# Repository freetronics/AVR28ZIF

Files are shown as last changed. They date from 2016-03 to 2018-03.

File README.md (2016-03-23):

Freetronics 28-Pin AVR ZIF Breakout
===================================
Copyright 2016 Freetronics Pty Ltd  
Freetronics site:  www.freetronics.com  
Freetronics email: info@freetronics.com  

Breakout for a 28-pin ZIF (Zero Insertion Force) for AVR microcontrollers,
with headers for ICSP and USB-to-Serial connections. Includes an onboard
crystal and LED on Arduino pin D13.

Features:

 * 28-pin ZIF socket
 * Header for FTDI-compatible USB-to-Serial cable
 * Header for 6-pin ICSP cable
 * Power source selection jumper
 * Power LED
 * LED on Arduino pin D13
 * Crystal and capacitors
 * Reset button

More information is available at:

  http://www.freetronics.com/avr28zif

INSTALLATION
------------
The design is saved as an EAGLE project. EAGLE PCB design software is
available from www.cadsoftusa.com free for non-commercial use. To use
this project download it and place the directory containing these files
into the "eagle" directory on your computer.

DISTRIBUTION
------------
The specific terms of distribution of this project are governed by the
license referenced below.

LICENSE
-------
Licensed under the TAPR Open Hardware License (www.tapr.org/OHL).
The "license" folder within this repository also contains a copy of
this license in plain text format.

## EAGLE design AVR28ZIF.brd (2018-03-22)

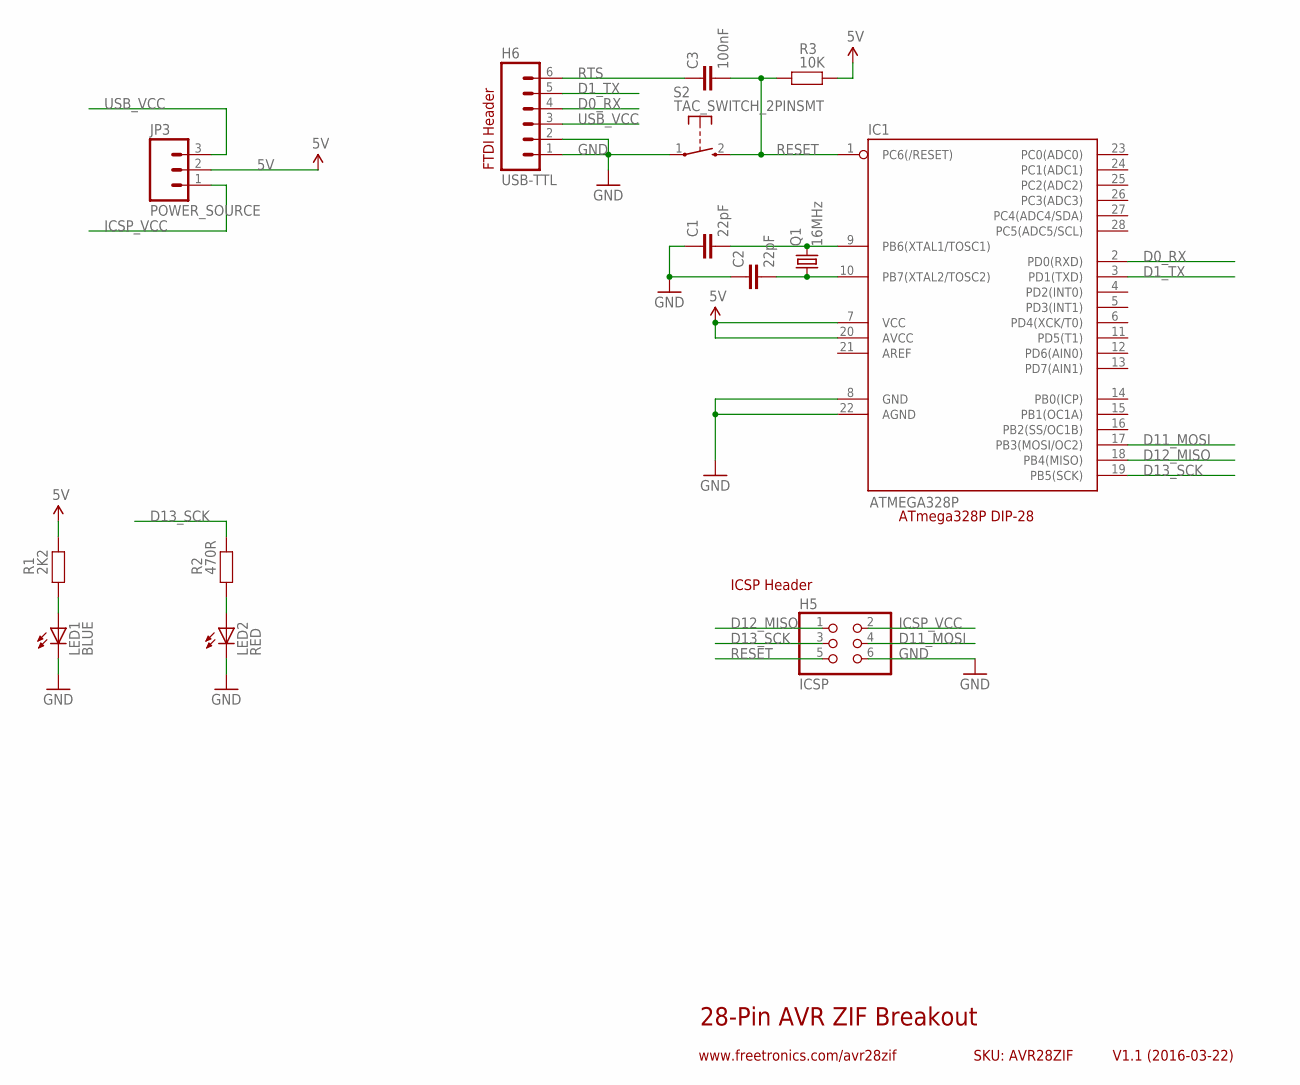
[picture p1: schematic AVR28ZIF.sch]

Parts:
C1, C2: 22pF; 0603
C3: 100nF; 0603
H5: ICSP; 2X03
H6: USB-TTL; 1X06
IC1: ATMEGA328P; DIL28-3-ZIF
JP3: POWER_SOURCE; 1X03
LED1: BLUE; LED-0603
LED2: RED; LED-0603
Q1: 16MHz; HC49US
R1: 2K2; 0603
R2: 470R; 0603
R3: 10K; 0603
S2: TAC_SWITCH_2PINSMT; TACTILE_SWITCH_SMD_2PIN_TINY

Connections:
5V: IC1.7 (VCC), IC1.20 (AVCC), JP3.2, R1.2, R3.2
D0_RX: H6.4, IC1.2 (PD0(RXD))
D1_TX: H6.5, IC1.3 (PD1(TXD))
D11_MOSI: H5.4, IC1.17 (PB3(MOSI/OC2))
D12_MISO: H5.1, IC1.18 (PB4(MISO))
D13_SCK: H5.3, IC1.19 (PB5(SCK)), R2.2
GND: C1.1, C2.1, H5.6, H6.1, H6.2, IC1.8 (GND), IC1.22 (AGND), LED1.C, LED2.C, S2.1
ICSP_VCC: H5.2, JP3.1
unnamed: C1.2, IC1.9 (PB6(XTAL1/TOSC1)), Q1.2
unnamed: C2.2, IC1.10 (PB7(XTAL2/TOSC2)), Q1.1
unnamed: LED1.A, R1.1
unnamed: LED2.A, R2.1
RESET: C3.2, H5.5, IC1.1 (PC6(/RESET)), R3.1, S2.2 (S)
RTS: C3.1, H6.6
USB_VCC: H6.3, JP3.3

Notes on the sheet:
28-Pin AVR ZIF Breakout
V1.1 (2016-03-22)
SKU: AVR28ZIF
www.freetronics.com/avr28zif
ATmega328P DIP-28
ICSP Header
FTDI Header

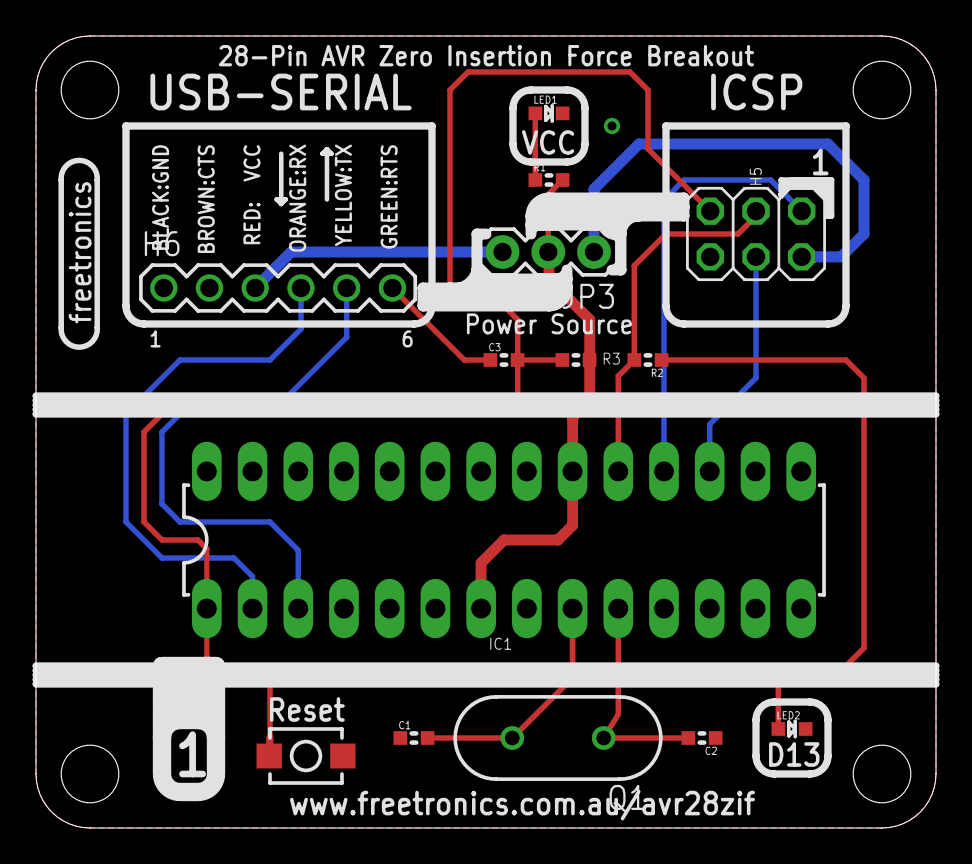
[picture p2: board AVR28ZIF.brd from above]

Board: 2 copper layers, 50.0 x 44.0 mm, 14 parts (0 on the bottom side), 15 nets.

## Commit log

2016-03-23 Initial import of project for v1.1 release
    [AVR28ZIF.brd, AVR28ZIF.sch]
2018-03-22 Updated part value labels
    [AVR28ZIF.brd]

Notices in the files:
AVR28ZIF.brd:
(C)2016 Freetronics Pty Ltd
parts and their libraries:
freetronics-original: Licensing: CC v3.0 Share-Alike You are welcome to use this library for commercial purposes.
